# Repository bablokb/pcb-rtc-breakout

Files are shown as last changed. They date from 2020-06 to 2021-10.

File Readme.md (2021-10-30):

PCB-RTC-Breakout
================

This is a minimalistic pcb to add a normal DS3131-breakout to a
Raspberry Pi:

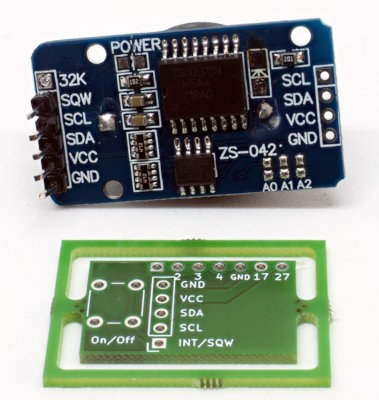
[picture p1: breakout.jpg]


Note that you have to remove the 32K-pin of the breakout and that
you might have to bend the other pins.

The pcb also adds a connector for a button. With the correct
configuration of the Pi you can now start and stop the Pi cleanly
with the button and start it in addition with the alarm of the RTC.

Note that the normal I2C-bus in not available when the button is
populated and configured.

Schematic
---------

The pcb just connects the I2C-lines of the RTC-breakout to GPIO17 and
GPIO27. Normal I2C is not available, since GPIO3 is needed for the
shutdown/restart function.

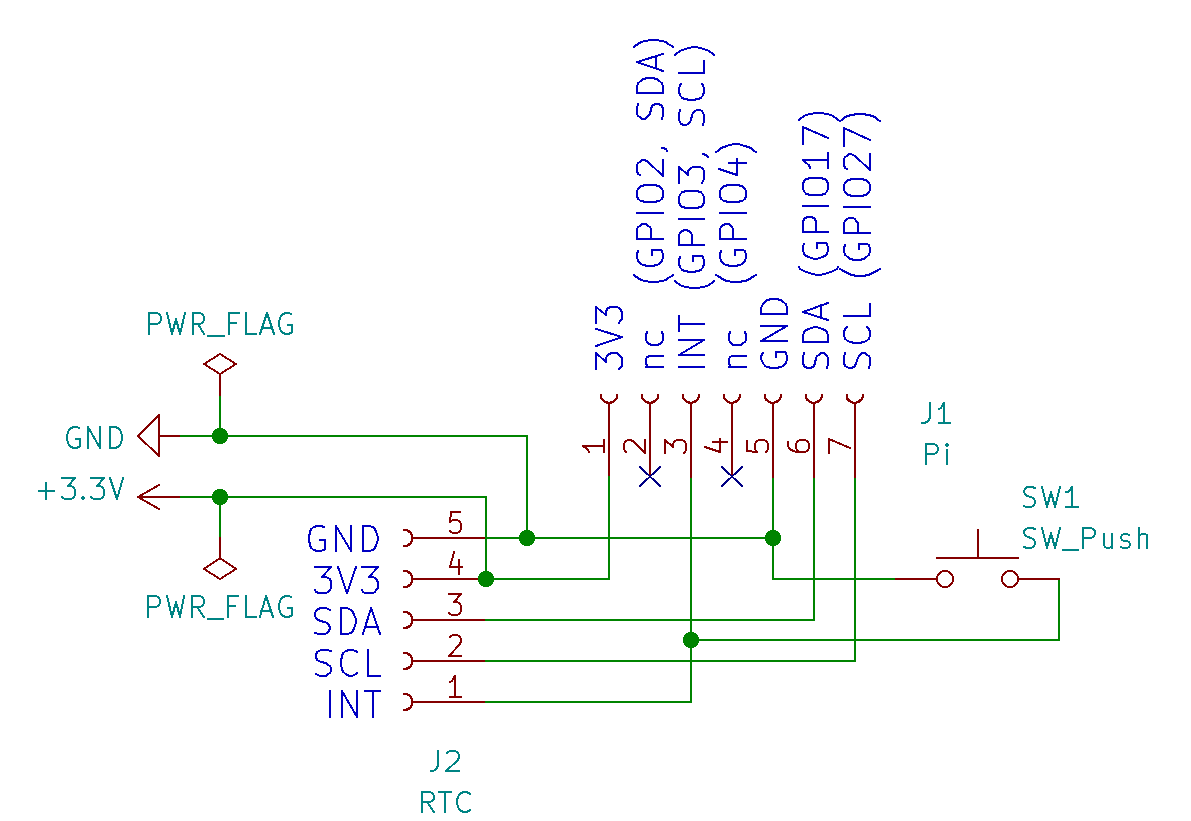
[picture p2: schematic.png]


PCB-production
--------------

The pcb-definition (Kicad-format) is in the directory `rtc-breakout.kicad`.
If your favorite pcb-factory does not support Kicad directly, you can
export to Gerber from within Kicad.

Configuration
-------------

In `/boot/config.txt`, add the following lines:

    dtoverlay=i2c-rtc-gpio,ds3231,i2c_gpio_sda=17,i2c_gpio_scl=27,wakeup-source
    dtoverlay=gpio-shutdown

The first line configures the RTC, the second line configures the button
to initiate a shutdown. If you do not cut power, a second press of the
button will restart the Pi.

License
-------

Shield: [![CC BY-SA 4.0][cc-by-sa-shield]][cc-by-sa]

This work is licensed under a
[Creative Commons Attribution-ShareAlike 4.0 International
License][cc-by-sa].

[][cc-by-sa]

[cc-by-sa]: http://creativecommons.org/licenses/by-sa/4.0/
[cc-by-sa-image]: https://licensebuttons.net/l/by-sa/4.0/88x31.png
[cc-by-sa-shield]:
https://img.shields.io/badge/License-CC%20BY--SA%204.0-lightgrey.svg

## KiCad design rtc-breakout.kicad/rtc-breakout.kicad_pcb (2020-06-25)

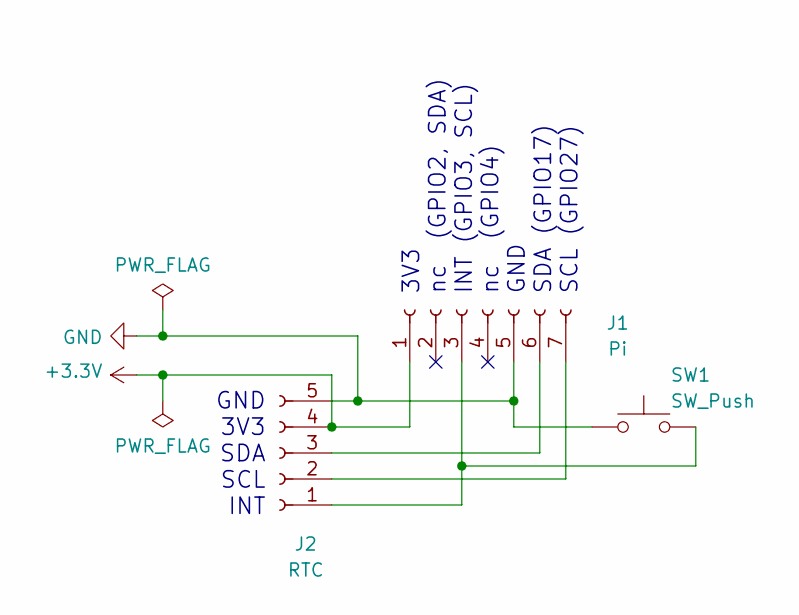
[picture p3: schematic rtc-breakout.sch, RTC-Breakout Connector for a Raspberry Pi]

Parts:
J1: Pi; PinSocket_1x07_P2.54mm_Vertical
J2: RTC; PinSocket_1x05_P2.54mm_Vertical
SW1: SW_Push; SW_PUSH_6mm

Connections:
+3V3: J1.1, J2.4
GND: J1.5, J2.5, SW1.1
unnamed: J1.3, J2.1, SW1.2
unnamed: J1.6, J2.3
unnamed: J1.7, J2.2

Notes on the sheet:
GND 3V3 SDA SCL INT
3V3 nc (GPIO2, SDA) INT (GPIO3, SCL) nc (GPIO4) GND SDA (GPIO17) SCL (GPIO27)

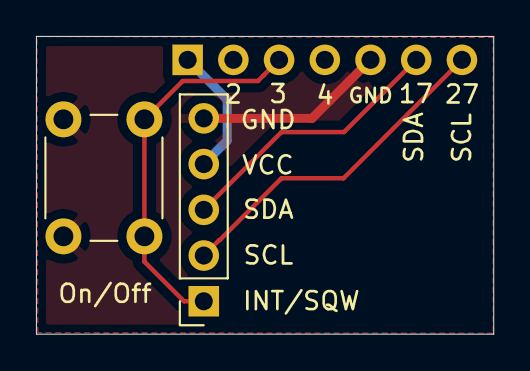
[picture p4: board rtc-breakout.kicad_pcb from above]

Board: 2 copper layers, 25.4 x 16.5 mm, 3 parts (1 on the bottom side), 5 nets.
